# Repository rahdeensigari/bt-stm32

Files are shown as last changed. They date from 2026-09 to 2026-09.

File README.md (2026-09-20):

# bt-stm32
An STM32 board with Bluetooth capabilities, made primarily for the sake of practice. I'm making this mainly so I can improve my PCB design skill all around, but mainly to practice making 4-layer boards, as well as to practice SMD soldering. I'm following along with [this](https://www.youtube.com/watch?v=nkHFoxe0mrU) tutorial (with my own changes, of course) to make this board using KiCAD. Firmware wise, I'm currently only using a basic script to flash the onboard LED on and off, but I will change this as I see fit, and all revisions will be updated to the repo.





If you want to make this for whatever reason, I would HIGHLY recommend using an SMD stencil instead of JLCPCB's PCBA, the gerbers and the BOM are in the [production](/production) folder. You can also find the firmware, which is currently just a basic LED blink, in the [firmware](/firmware) folder, and the PCB files themselves in the [pcb](/pcb) folder.

Some general cost estimates (USD):
- PCB: $7.10
- Stencil: $7.22
- LCSC Components: $31.01

If you want to use the RF capabilities, you will need an external antenna. Just search up female U.FL antenna and you will be able to find a lot of antennas that will work perfectly fine.

*Submitted to Forge (Hackclub)*
*Credit to Phil's Lab and Claude*

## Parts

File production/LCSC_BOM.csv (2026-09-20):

Index | LCSC# | MPN | Manufacturer | Package | Customer # | Description | RoHS | Quantity | MOQ | Multiple | Unit Price($) | Extended Price($) | Product Link
1 | C184029 | LQW15AN10NJ00D | muRata | 0402 |  | 500mA 10nH ±5% 170mΩ Unshielded Inductor 0402 Fixed Inductors RoHS | yes | 20 | 20 | 20 | 0.0420 | 0.84 | https://www.lcsc.com/product-detail/C184029.html
2 | C843260 | NX2016SA-32MHZ-STD-CZS-5 | NDK | SMD2016-4P |  | SMD2016-4P Crystals | yes | 5 | 5 | 5 | 0.3534 | 1.77 | https://www.lcsc.com/product-detail/C843260.html
3 | C54930595 | NXPC32.768KAE125F-BT-5 | NSK | SMD2012 |  | ±20ppm 12.5pF ±20ppm SMD2012 Crystals | yes | 1 | 1 | 1 | 0.4317 | 0.43 | https://www.lcsc.com/product-detail/C54930595.html
4 | C911135 | STM32WB55CEU6 | ST | UFQFPN-48(7x7) |  | ARM Cortex-M4 32 Bit 1.71V~3.6V UFQFPN-48(7x7) RF Transceiver ICs RoHS | yes | 1 | 1 | 1 | 8.5087 | 8.51 | https://www.lcsc.com/product-detail/C911135.html
5 | C7519 | USBLC6-2SC6 | ST | SOT-23-6L |  | 17VC Clamp 5A Ipp ESD DIODE SOT-23-6L | yes | 5 | 5 | 5 | 0.1782 | 0.89 | https://www.lcsc.com/product-detail/C7519.html
6 | C11337 | TLV70033DDCR | TI | SOT-23-5 |  | 3.3V Positive Fixed SOT-23-5 Voltage Regulators - Linear, Low Drop Out (LDO) Regulators RoHS | yes | 5 | 5 | 5 | 0.1739 | 0.87 | https://www.lcsc.com/product-detail/C11337.html
7 | C49234124 | HX 3x4x2-2P-1.6N TACTILE SWITCH | hanxia | SMD,4x3mm |  | Tactile Switch SPST 160gf 2mm SMD (SMT) Tab 4mm x 3mm Surface Mount | yes | 20 | 20 | 20 | 0.0240 | 0.48 | https://www.lcsc.com/product-detail/C49234124.html
8 | C25091 | 0402WGF2200TCE | UNI-ROYAL | 0402 |  | 220Ω ±1% 62.5mW 0402 Thick Film Resistor | yes | 100 | 100 | 100 | 0.0033 | 0.33 | https://www.lcsc.com/product-detail/C25091.html
9 | C105872 | RC0402FR-075K1L | YAGEO | 0402 |  | 5.1kΩ 62.5mW 50V Thick Film Resistor ±100ppm/℃ ±1% 0402 Chip Resistor - Surface Mount RoHS | yes | 100 | 100 | 100 | 0.0026 | 0.26 | https://www.lcsc.com/product-detail/C105872.html
10 | C77108 | LQG15HS2N7S02D | muRata | 0402 |  | 800mA 2.7nH 150mΩ Multilayer inductor 0402 Fixed Inductors RoHS | yes | 50 | 50 | 50 | 0.0216 | 1.08 | https://www.lcsc.com/product-detail/C77108.html
11 | C963809 | EBLS201209-100K | HYHONGYEX | 0805 |  | 15mA 10uH ±10% 1.15Ω Multilayer inductor 0805 Fixed Inductors RoHS | yes | 20 | 20 | 20 | 0.0389 | 0.78 | https://www.lcsc.com/product-detail/C963809.html
12 | C60474 | CC0402KRX7R7BB104 | YAGEO | 0402 |  | 100nF ±10% 16V Ceramic Capacitor X7R 0402 | yes | 100 | 100 | 100 | 0.0050 | 0.50 | https://www.lcsc.com/product-detail/C60474.html
13 | C598199 | U.FL-R-SMT-1(01) | HRS | SMD |  | Connector Receptacle IPEX Male Pin 50Ω Surface Mount | yes | 1 | 1 | 1 | 3.4577 | 3.46 | https://www.lcsc.com/product-detail/C598199.html
14 | C492398 | PM127V-11-04P-H34 | XFCN | Through Hole,P=1.27mm |  | Female Header 4 Position 1.27mm Pitch Single Row Through Hole -40℃~+105℃ | yes | 5 | 5 | 5 | 0.0988 | 0.49 | https://www.lcsc.com/product-detail/C492398.html
15 | C22438072 | HX PM1.27-1x6P ZC | hanxia | Through Hole,P=1.27mm |  | Female Header 6 Position 1.27mm Pitch Single Row Through Hole -40℃~+105℃ | yes | 5 | 5 | 5 | 0.1270 | 0.64 | https://www.lcsc.com/product-detail/C22438072.html
16 | C2894897 | HC-TYPE-C-16P-01A | HCTL | SMD |  | USB-C (USB TYPE-C) Receptacle Connector 16 Position Surface Mount, Right Angle | yes | 5 | 5 | 5 | 0.0848 | 0.42 | https://www.lcsc.com/product-detail/C2894897.html
17 | C531364 | DLF162500LT-5028A1 | TDK | SMD-4P,1.6x0.8mm |  | 50Ω 0.33dB SMD-4P,1.6x0.8mm RF Filters RoHS | yes | 5 | 5 | 5 | 0.1252 | 0.63 | https://www.lcsc.com/product-detail/C531364.html
18 | C21260817 | YLED0402R | YONGYUTAI | 0402 |  | Red 645nm LED Indication - Discrete 1.8V~2.4V 0402 | yes | 50 | 50 | 50 | 0.0134 | 0.67 | https://www.lcsc.com/product-detail/C21260817.html
19 | C76909 | GJM1555C1HR30WB01D | muRata | 0402 |  | 0.3pF 50V Ceramic Capacitor C0G 0402 | yes | 20 | 20 | 20 | 0.0421 | 0.84 | https://www.lcsc.com/product-detail/C76909.html
20 | C88902 | GJM1555C1HR80WB01D | muRata | 0402 |  | 0.8pF 50V Ceramic Capacitor C0G 0402 | yes | 20 | 20 | 20 | 0.0404 | 0.81 | https://www.lcsc.com/product-detail/C88902.html
21 | C161306 | GJM1555C1H130FB01D | muRata | 0402 |  | 13pF ±1% 50V Ceramic Capacitor C0G 0402 | yes | 10 | 10 | 10 | 0.0537 | 0.54 | https://www.lcsc.com/product-detail/C161306.html
22 | C106200 | CC0402JRNPO9BN101 | YAGEO | 0402 |  | 100pF ±5% 50V Ceramic Capacitor NP0 0402 | yes | 100 | 100 | 100 | 0.0044 | 0.44 | https://www.lcsc.com/product-detail/C106200.html

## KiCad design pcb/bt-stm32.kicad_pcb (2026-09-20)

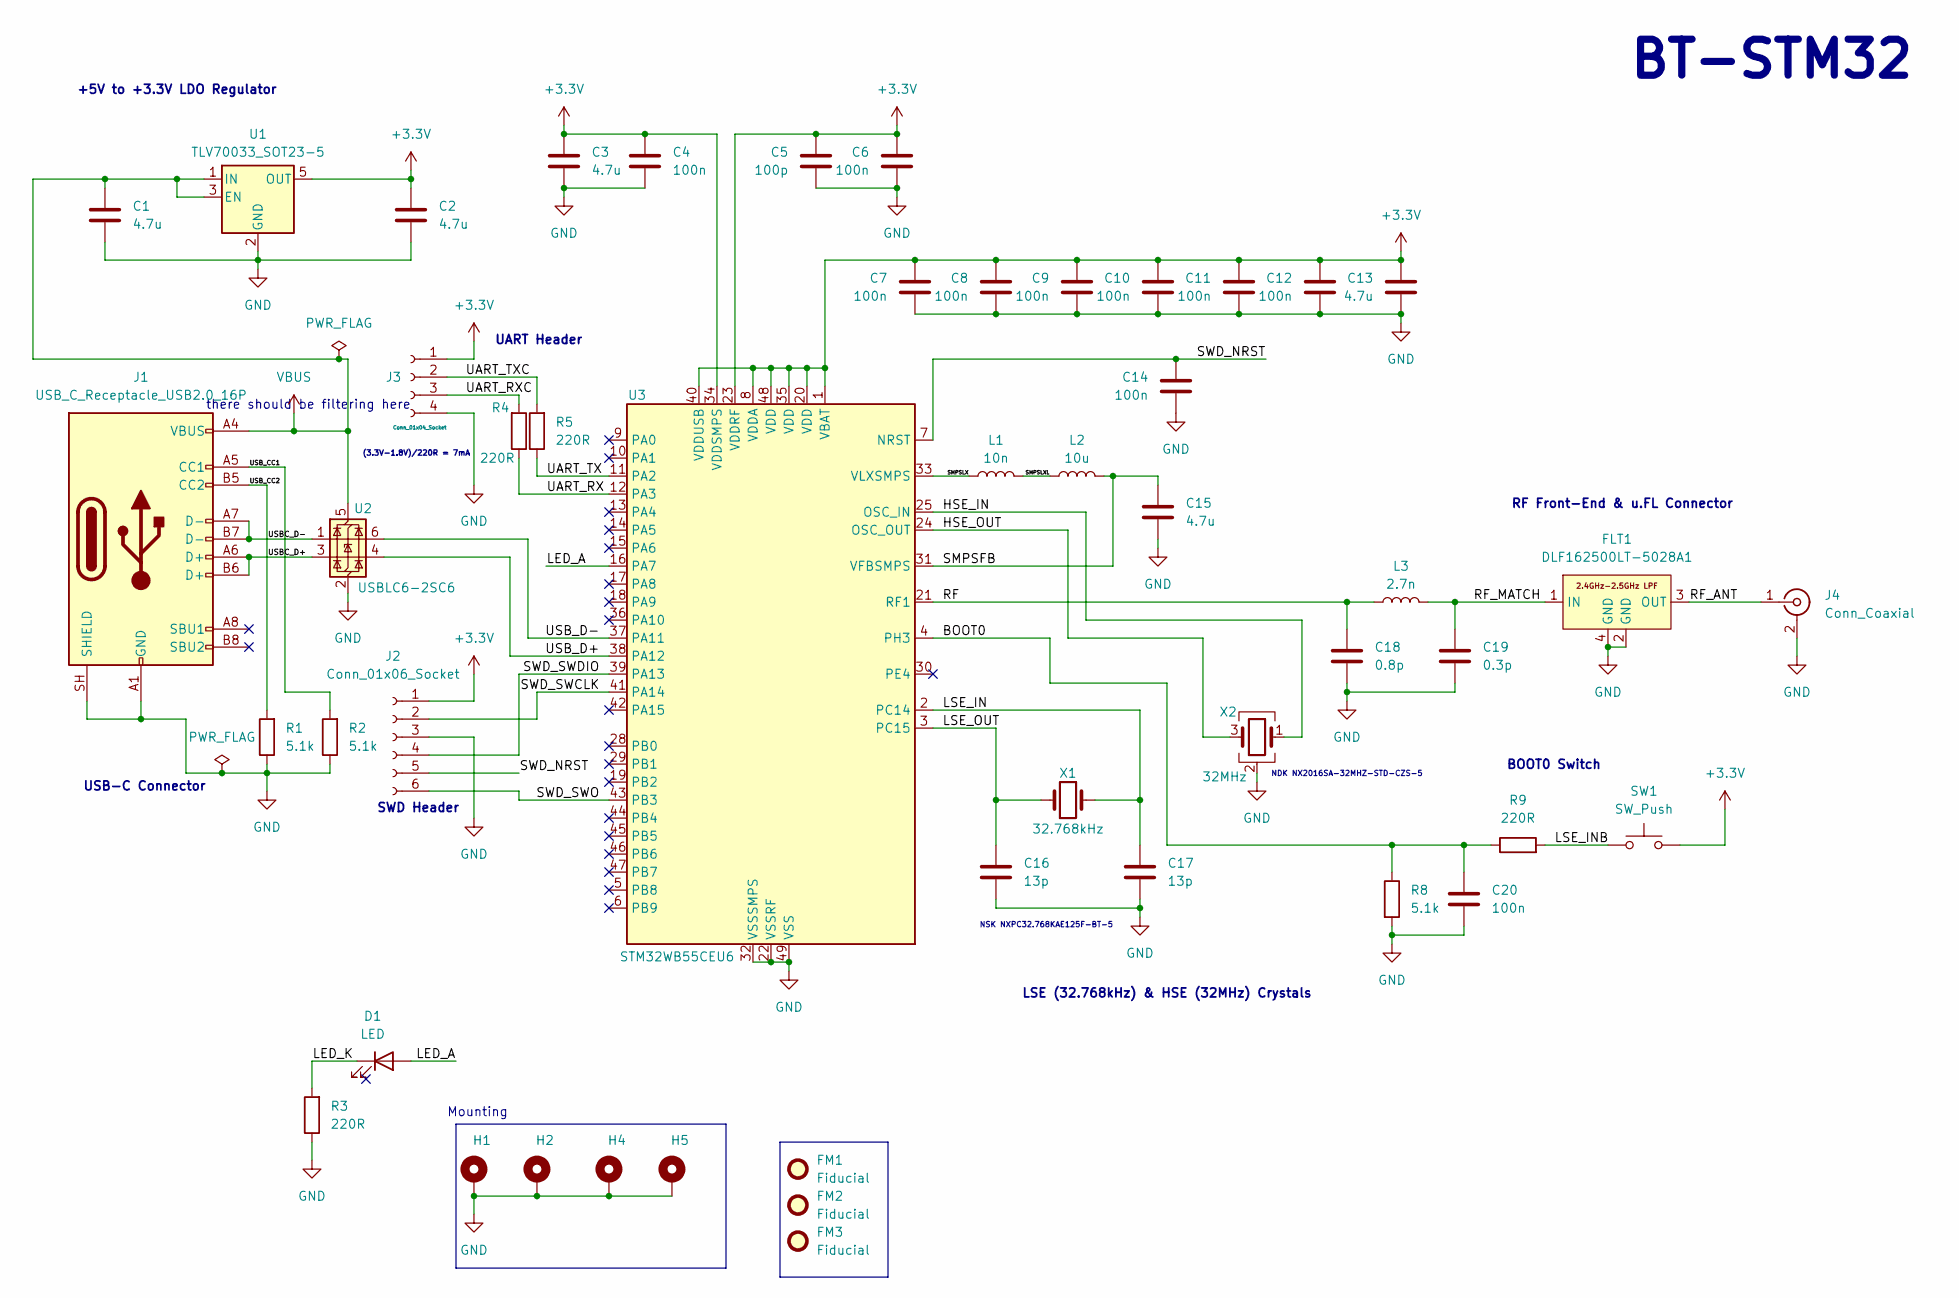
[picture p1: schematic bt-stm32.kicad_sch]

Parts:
C1, C2, C3: 4.7u; C_0603_1608Metric; Part Number C1705
C4, C6, C7, C8, C9, C10, C11, C12, C14, C20: 100n; C_0402_1005Metric; Part Number C60474
C5: 100p; C_0402_1005Metric; Part Number C106200
C13, C15: 4.7u; C_0603_1608Metric; Part Number C368809
C16, C17: 13p; C_0402_1005Metric; Part Number C161306
C18: 0.8p; C_0402_1005Metric; Part Number C88902
C19: 0.3p; C_0402_1005Metric; Part Number C76909
D1: LED; LED_0402_1005Metric; Part Number C21260817
FLT1: DLF162500LT-5028A1; Part Number C531364
FM1, FM2, FM3: Fiducial; Fiducial_1mm_Mask2mm
H1, H2, H4, H5: MountingHole_Pad; MountingHole_2.2mm_M2_Pad_Via
J1: USB_C_Receptacle_USB2.0_16P; USB_C_Receptacle_HCTL_HC-TYPE-C-16P-01A; Part Number C2894897
J2: Conn_01x06_Socket; PinHeader_1x06_P1.27mm_Vertical; Part Number C22438072
J3: Conn_01x04_Socket; PinHeader_1x04_P1.27mm_Vertical; Part Number C492398
J4: Conn_Coaxial; U.FL_Hirose_U.FL-R-SMT-1_Vertical; Part Number C598199
L1: 10n; L_0402_1005Metric; Part Number C184029
L2: 10u; L_0805_2012Metric; Part Number C963809
L3: 2.7n; L_0402_1005Metric; Part Number C77108
R1, R2, R8: 5.1k; R_0402_1005Metric; Part Number C105872
R3, R4, R5, R9: 220R; R_0402_1005Metric; Part Number C25091
SW1: SW_Push; SMD,4x3mm; Part Number C49234124
U1: TLV70033_SOT23-5; SOT-23-5; Part Number C11337
U2: USBLC6-2SC6; SOT-23-6; Part Number C7519
U3: STM32WB55CEU6; QFN-48-1EP_7x7mm_P0.5mm_EP5.6x5.6mm; Part Number C911135
X1: 32.768kHz; Crystal_SMD_2012-2Pin_2.0x1.2mm; Part Number C54930595
X2: 32MHz; Crystal_SMD_2016-4Pin_2.0x1.6mm; Part Number C843260

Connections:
+3.3V: C2.1, C3.1, C4.1, C5.1, C6.1, C7.1, C8.1, C9.1, C10.1, C11.1, C12.1, C13.1, J2.1, J3.1, SW1.2, U1.5 (OUT), U3.1 (VBAT), U3.8 (VDDA), U3.20 (VDD), U3.23 (VDDRF), U3.34 (VDDSMPS), U3.35 (VDD), U3.40 (VDDUSB), U3.48 (VDD)
/BOOT0: C20.1, R8.1, R9.1, U3.4 (PH3)
/HSE_IN: U3.25 (OSC_IN), X2.1
/HSE_OUT: U3.24 (OSC_OUT), X2.3
/LED_A: D1.2 (A), U3.16 (PA7)
/LED_K: D1.1 (K), R3.2
/LSE_IN: C17.1, U3.2 (PC14), X1.1
/LSE_INB: R9.2, SW1.1
/LSE_OUT: C16.1, U3.3 (PC15), X1.2
/RF: C18.1, L3.2, U3.21 (RF1)
/RF_ANT: FLT1.3 (OUT), J4.1 (In)
/RF_MATCH: C19.1, FLT1.1 (IN), L3.1
/SMPSFB: C15.1, L2.1, U3.31 (VFBSMPS)
/SMPSLX: L1.2, U3.33 (VLXSMPS)
/SMPSLXL: L1.1, L2.2
/SWD_NRST: C14.1, J2.5, U3.7 (NRST)
/SWD_SWCLK: J2.2, U3.41 (PA14)
/SWD_SWDIO: J2.4, U3.39 (PA13)
/SWD_SWO: J2.6, U3.43 (PB3)
/UART_RX: R4.1, U3.12 (PA3)
/UART_RXC: J3.3, R4.2
/UART_TX: R5.1, U3.11 (PA2)
/UART_TXC: J3.2, R5.2
/USBC_D+: J1.A6 (D+), J1.B6 (D+), U2.3 (I/O2)
/USBC_D-: J1.A7 (D-), J1.B7 (D-), U2.1 (I/O1)
/USB_CC1: J1.A5 (CC1), R2.2
/USB_CC2: J1.B5 (CC2), R1.2
/USB_D+: U2.4 (I/O2), U3.38 (PA12)
/USB_D-: U2.6 (I/O1), U3.37 (PA11)
GND: C1.2, C2.2, C3.2, C4.2, C5.2, C6.2, C7.2, C8.2, C9.2, C10.2, C11.2, C12.2, C13.2, C14.2, C15.2, C16.2, C17.2, C18.2, C19.2, C20.2, FLT1.2 (GND), FLT1.4 (GND), H1.1 (1_1), H2.1 (1_1), H4.1 (1_1), H5.1 (1_1), J1.A1 (GND), J1.A12 (GND), J1.B1 (GND), J1.B12 (GND), J1.SH (SHIELD), J2.3, J3.4, J4.2 (Ext), R1.1, R2.1, R3.1, R8.2, U1.2 (GND), U2.2 (GND), U3.22 (VSSRF), U3.32 (VSSSMPS), U3.49 (VSS), X2.2 (G), X2.4 (G)
VBUS: C1.1, J1.A4 (VBUS), J1.A9 (VBUS), J1.B4 (VBUS), J1.B9 (VBUS), U1.1 (IN), U1.3 (EN), U2.5 (VBUS)

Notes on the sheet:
USB-C Connector
NSK NXPC32.768KAE125F-BT-5
UART Header
Mounting
there should be filtering here
BT-STM32
+5V to +3.3V LDO Regulator
SWD Header
(3.3V-1.8V)/220R = 7mA
NDK NX2016SA-32MHZ-STD-CZS-5
RF Front-End & u.FL Connector
LSE (32.768kHz) & HSE (32MHz) Crystals
BOOT0 Switch

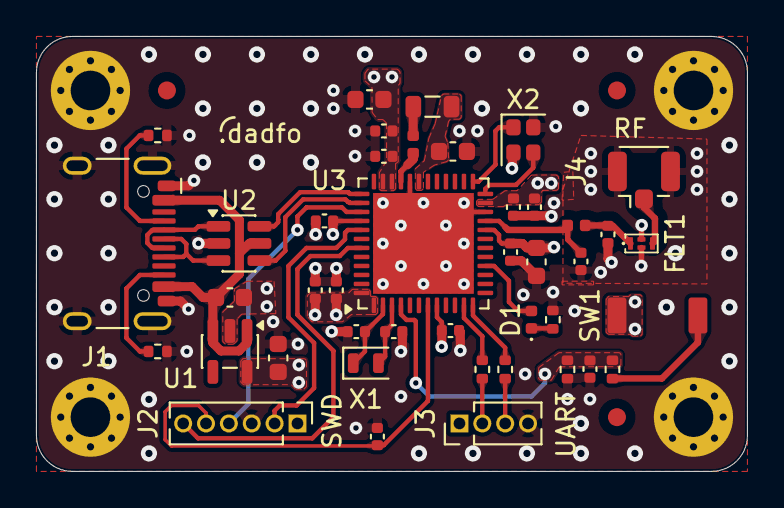
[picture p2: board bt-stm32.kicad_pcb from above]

Board: 4 copper layers, 39.5 x 24.2 mm, 49 parts (0 on the bottom side), 31 nets.

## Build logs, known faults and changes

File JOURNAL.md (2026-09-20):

# August 8 - Start

This is mainly going to serve as a practice exercise for creating 4-layer pcbs. As mentioned in the README, I'm following along with [this](https://www.youtube.com/watch?v=nkHFoxe0mrU) tutorial to create the base board (that's why this is marked as T4 on forge) but I will make some changes to the design as I see fit, and will try to do the majority of steps myself. This board is going to use the STM32WB55CEU6 MCU to allow for Bluetooth communication. I'm also going to be using KiCAD to actually create the schematic and design the PCB. With that out of the way, I'm going to jump straight into designing this. First, I imported the MCU symbol in KiCAD:



Then I also created a new project in STM32CubeMX, which is a software that allows for easier assignment of pins depending on your needs:



Back in KiCAD, I added all of the decoupling caps. These were mostly based off [this](https://www.st.com/resource/en/application_note/an5165-how-to-develop-rf-hardware-using-stm32wb-mcus-stmicroelectronics.pdf) application note. To keep the board relatively simple, I merged VDD, VDDA, and VDDUSB, as well as VBAT of course. The tutorial also didn't add a second 100pF to the VDDRF pin, but I added it just for good measure.



Next I implemented SMPS, this basically helps improve low power performance. I did this by tying the VLXSMPS and VFBSMPS pins together connected by two inductors and a capacitor as specified by the documentation:



Then, I added the crystal oscillators. This MCU is kind of weird in that it requires both a high-speed and low-speed crystal oscillator. The high-speed crystal actually doesn't require any load capacitors as well. For the low-speed crystal's load capacitors, I'm not going to actually add their values until I decide which crystal I'm going to be using.



**Total Time Spent: 1 Hour**

# August 14 - RF Hardware and USB-C

Next up is the RF hardware. This is pretty new to me so I'm going to rely pretty heavily on the tutorial. STM's official application notes (AN5165) say to setup the RF hardware like this:



Using that as a reference, I first setup the matching network. This basically uses pi-network impedance matching to keep the impedance equal on both sides, preventing signal reflection.



Next, I added a low pass filter. The specific model that the application note suggests is DLF162500LT-5028A1, which didn't have a schematic and footprint available, meaning I had to make my own:




Then I added a coaxial connector symbol for the UFL connector.
 


Next I broke out the SWD pins for debugging as well as the reset pin in STM32CubeMX:



Then I added it into the schematic. I'm using a 6 pin connector while the video uses something called a tag-connect, but tag-connect wires are expensive so I'm just going to stick with a simple connector.



Added boot:



Next I added USB-C, this is pretty standard but I also added an ESD protector, which is not something I've actually done in the past:



To find a good LDO voltage regulator, I used STM32CubeMX to find the current requirements for the MCU.



Since it is so low, I can get away with using an LDO voltage regulator. The specific one I'm using is the MIC5365-3.3YD5. I'm using 4.7uF caps to shorten the BOM.



**Total Time Spent: 1.97 Hours**

# August 23 - UART, LED indicator

Next I'm going to add some peripherals, specifically a UART header. This is pretty standard, I'm not going to go too overkill here. I'm using a socket because it's cleaner than pins:




I'm also going to add an LED power indicator. Normally I just hook this up to power, but the tutorial actually uses a timer channel to control it through PWM, which is something new to me. The tutorial uses the PA7 pin, I'm going to use PB9 instead because my schematic is kind of cluttered in the PA7 area:



For the LED, in order for it work properly I need around 220R, so I'm just going to change all the other 100R resistors to 220R as well to simplify the BOM.



The schematic itself is now complete, I just need to clean some stuff up. I added some labels and a title block, as well as fixing KiCAD's automatic annotations. Additionally I assigned 12.5p load caps to the LSE crystal (later changed to 13p as LCSC doesn't have 12.5p)



I then went ahead and assigned footprints to all of my symbols. I also just removed the series resistors for the crystals. One thing I did decide on doing was to change the LDO to a cheaper version (TI TLV70033DDCR). I also updated my symbol fields to include the links to all the parts that I will be using to make ordering them easier (this took up the majority of the time).



I also added some net classes, and that basically finishes the entire schematic.

**Total Time Spent: 2.833 Hours**

# August 24 - Starting the PCB

I'm finally going to start actually designing the PCB. First, I need to do some basic setup. Obviously, this is going to be a 4-layer board (that's literally the reason I'm doing this), and since I'm using RF hardware I also need to make it impedance controlled. I did this by checking the box for it in KiCAD. I also changed the layer thickness and material according to JLCPCB's specs:



I also updated the design rule constraints based off of what JLCPCB allows:



I spent a lot of time after trying to figure out impedance, but it's late so I'll do that later.

**Total Time Spent: 0.66 Hours**

# August 25 - Impedance Research + PCB

I did some [research](https://www.youtube.com/watch?v=0fteCxn5XXA) on impedance so I can find out how to actually calculate the right impedance trace width for this board. From that video, I calculated that I'm going to need a trace width of 0.3586mm. I did this by using [JLCPCB's impedance calculator](https://jlcpcb.com/pcb-impedance-calculator), which greatly simplifies the process of calculating impedance as they have all the dielectric constant of their different board stack-ups built-in. For some reason, the main stack-up type they use is the last option on the calculator, which kind of confused me at first. I also calculated the impedance of the USB differential pair, which, with a target resistance of 90R and spacing of 0.15mm, turned out to be 0.2474mm. I then proceeded to add these as predefined track sizes, along with all the other predefined values that were added from the video, before adding all of my components to the PCB editor:




First thing I did was go into my schematic and add some netlabels in places where I had forgotten them, pretty straightforward. I also didn't have a lot of the 3D models for the components so I went ahead and added all of the ones I didn't have. For the USB-C model, the specific one that I'm going to use doesn't have a STEP model available, so I had to use one of KiCAD's built in ones that didn't quite match but is good enough for this purpose for me to not care.



**Total Time Spent: 0.817 Hours**

# August 29 - Component Layout

The first thing I did was add colors to my net classes to help me during laying out/doing traces on the PCB.



For the actual layout of the PCB, I'm trying a different approach that was used in the video, and that's to first create a very rough layout of the major components and build from there. Before what I did was try to spread out from the MCU to the rest of the board, but this approach feels like I'm planning the entire layout of the board better. The board is going be very long compared to its width, with the USB connector on one side and the RF antenna on the other. I'm kind of just placing stuff both where the video says to place it and where I think it would fit the best.

I originally had the SWD socket lined up vertically like how the video did it with tag connects:



However, after adding the ESD protection on the USB port, I realized that drawing the traces around the socket wouldn't be optimal, so I just moved it down horizontally aligned with the UART socket:



A good workflow that I'm finding effective is to do the thing where you layout all the major components first, but I'm also cleaning up component placements in relation to each other while I'm creating the initial layout. (RF):



Load caps for the LSE crystal. I might change the orientation of the GND pins on the resistors later:



I also realized that I had gotten a couple of caps (C13, C15) wrong in the BOM while I was laying out the components for SMPS:



That's all the important components done, I'll move on to decoupling caps in my next session.



**Total Time Spent: 1.7 Hours**

# August 30 - Smaller Components and Finished Layout

I'm going to start today by placing the decoupling capacitors. I normally do these first, but the video is demanding for them to be done after all the major components have already been laid out. The goal with decoupling capacitors is to have them as close to the MCU as possible, as the less trace between the pins means there's going to be less inductance and noise. I tried to do these myself then go back to the video to see the optimal way to place it. One especially difficult part to place capacitors were pins 34 and 35, which was near the SMPS components. I had to place both of them vertically and shift the SMPS components over slightly in order to make it work. I also had one extra capacitor that the video left out (C6):



At first I thought this would work fine, but then I realized that I would also need a bulk decoupling capacitor for C4. I unfortunately could not figure out how to place them so I did have to resort to seeing what the video did, which was to route the smaller caps in parallel with the bulk decoupling cap at the end:



Everything else was really straightforward, here are the decoupling caps with my placements:



One note, for some reason the video didn't add the second bulk decoupling cap yet, which I added with my other caps. I'm not sure as to why he didn't do this, but I'm guessing it is because it's less important. After looking at what he did, pretty much everything else was the same, except for one of the decoupling caps near the bottom being moved a bit further up to allow the crystal to be closer to the MCU, which I implemented as well:



(Note: He did add it later as well)

Next up, I did the LDO regulator. I tried it myself and I got something like this, with the IC right above the ESC protection and the capacitors around the LDO regulator:



The more optimal design however is to move the LDO regulator below the ESD protector and rotate it 90 degrees like this. This fills in a perfectly shaped dead space near the bottom of my PCB:

 

Then I added the CC1 and CC2 pulldown resistors, not much to say here, these are pretty straightforward. I just have them parallel to the connector so they look better and so it's easier to route:



NRST capacitor. Again, this is pretty simple. I just had to keep in mind how it would be connected from the MCU to the SWD socket:



Next was the LED, and it turns out that my current pinout made routing it a pain, as the traces had to pass through all of the LSE/UART components to actually get to the LED. Instead, I changed the pin from PB9 to PA7, which made the routing a whole lot easier:



Last for the layout, I added the boot switch. I decided to place this in a dead space near the far bottom right of the PCB. Again, not really anything notable, I just added the resistors and caps:



With that though, the layout is complete:




**Total Time Spent: 2.033 Hours**

# August 31 - Board Outline, Mounting Holes, Fiducial Markers

First thing I did today was the board outline. This was really simple, I just defined a basic outline that I can change later on if I need to:



I also added my author indicator:



After that, I was ready to move on to routing. The stack up that the video uses is SIGNAL - GND - GND - SIGNAL but this isn't the standard, so I want to try using SIGNAL - GND - POWER - SIGNAL instead.




Next, I added some mounting holes and fiducial markers in my schematic then laid them out on my PCB. For some reason, the video is tying the mounting holes to ground, which I don't think is necessary but I'll follow along. Also note that because this is a demo board I do not care at all about where I place these:




**Total Time Spent: 0.583 Hours**

# September 4 - Designators and Traces

I started traces. The workflow that the video says to use is to do vias first. Before I started traces though, I wanted to clean up the component indicators, as most actual professional PCBs do not include designators for every single component. Additionally, I have no plans to hand solder this board, so the indicators aren't really helping me either. Instead, I decided to keep only the ones that I deemed important:



With the majority of the designators out of the way, I could re-place some of my components to make the board more uniform, and also add some extra silkscreen notes to important components. The reason I'm doing this first is so I know where I can't place vias. With these changes, I also actually have room for 4 mounting holes now:



As mentioned before, I started with vias. One thing I struggled with was figuring out how to copy and paste the same trace length between different pads and actually get the end of the trace to snap to other pad. I figured out after a bit of research that I needed to set object snapping to all layers for it to actually work. After I figured that out though it was pretty straightforward. I connected the traces for all of the components that only needed one via but left the vias that needed fill zones unconnected for now:



I also went ahead and did the same thing for 3v3:



Now I can move on to actual routing. I started with the RF traces. These were pretty straightforward, but one thing that I'm kind of uncertain of is that I need to have a smaller trace at the actual pin on the STM32 going up to a wider trace (impedance), which I don't really like:




After the RF traces, I did the crystal routing. There was nothing really noteworthy to talk about here, except for the fact that I did have to move some of the capacitors on the LSE crystal to make routing a little bit easier:



The big thing I realized though was how stupid of a decision it was to do SIGNAL - GND - POWER - SIGNAL for this board. Because of this, I'm probably going to switch to SIGNAL - GND - GND - SINGAL tomorrow.

**Total Time Spent: 1.6 hours**

# September 5 - Fixed Stackup, More Traces

As mentioned yesterday, my old stackup was not optimal at all. Because of this, I'm going to change it to SIGNAL - GND - GND - SINGAL. This was a pretty easy fix.

After the crystal routing, I did SMPS. Again, pretty straightforward. An interesting thing I noticed was to start with the largest possible trace width (so 0.25mm) then scale up to a larger width like 0.5mm to reduce impedance.



Next is the SWD traces, and these are just a pain. I faced a couple of problems when trying to route these:

1. The USB differential pair pads are right next to the SWD pads.
2. There are two sets of decoupling capacitors above and below the SWD pads.
3. The actual socket is very far away, and there are a lot of components blocking the path to it.
4. I wanted to impedance match the traces.

Although I don't have any screenshots of it, I did actually try to move the socket up to the top of the PCB, but this only made it harder to route everything. While I had it moved to the top, I realized I actually messed up the order of the pins, and changed it to what the standard order should be:



Eventually, I moved the socket back down and tried routing the traces through the bottom layer with vias instead. So far this seems to work fine. I decided that I'm going to ignore impedance matching for this, as it is not necessary for SWD to the level that it is necessary for RF traces. It's late, so I'll continue this tommorow:



**Total Time Spent: 1.33 Hours**

# September 6 - Continued Routing Traces

I started today by finishing the SWD traces. I didn't need to do any of the stuff with vias for the other traces, but I might have to change some of them if there is interference with other routing:



Next, I went ahead and did the USB differential pairs. These aren't perfectly differential (I changed some parts of the traces to make it neat), but for short lengths like these, it really doesn't matter too much:



That's all the critical traces done. With those out of the way, I can move on to the more low priority stuff. First, I routed the BOOT0 pins. These were really annoying to route. First, to even break it out from the MCU, I had to shift the LSE over, as in its current position it was blocking the BOOT0 pin from being broken out. Then, the next problem was that the NRST trace was blocking the BOOT0 trace. To fix this, I had to use a via to route the trace to the bottom layer and another via to bring it back up. I also connected the capacitors and resistors with a copper pour:



Then, I routed a couple of the easier traces, for example LED and UART. Nothing really notable to state for these, they were pretty straightforward:



I also added some ground return vias to the BOOT0 vias:



I also routed the CC connections on the USB header. Although not necessary, I did take some care to make the traces equal length:



That's actually all of the signal connections done, now all that's left are the power and ground connections. First, I started with the VBUS traces. I did have to remove the via on the top GND pad on the LDO regulator:



Then I worked on routing 3v3. The way I'm going to do this is by using a copper pour on the bottom layer connecting all the vias together, then individual copper pours connecting the 3v3 vias together:




I also did a similar thing with the GND pads using the two middle copper pour layers:



**Total Time Spent: 1.94 Hours**

# September 19 - Finished PCB!

The first thing I did was finish the 3v3 pours:





With that done, I'm actually going to take a different approach do doing the GND connections. Instead of individual pours like I did with 3v3, I'm just going to fill the entire top layer with a GND pour that connects all of the GND vias to each other. To do this, I first deleted all the existing pours and connections that I had before:



Then I added the actual GND pour to the GND plane:



This was a pain, and it's not quite perfect, so let me go over what took so long for this. First of all, I had to change the position of most of the GND vias, because they were only partially in the pour zones. This was easy enough, it just took a bit. The main difficulty though was the RF section, because having more copper around it changes the impedance. The best way to fix this is by adding clearance around the RF section, specifically 3x the thickness of the dielectric layers, which was 0.6mm for me. What took me so long was figuring out how to do this, because the video changes the clearance of the entire GND pour, but since he was using PCBWay, the dielectric layers were thinner, allowing him to use less clearance. 0.6mm of clearance around the entire board is just not acceptable, so I spent a long time figuring out how to actually do this. My initial thought was a keep out zone, but this just prevented me from connecting the vias effectively. Eventually, I decided on adding a custom rule area then defining a 0.6mm clearance for anything in that area. (Credit to Claude for figuring this out):




Next, since I have 3 GND planes, I'm going to add some via stitching to minimize impedance across all of the planes. Using this formula:



I calculated the ideal spacing for my vias, which was around 3mm:



With that value, I added stitching vias throughout the entire board:



The PCB is pretty much done now. I added teardrops to all of the pads/traces. I might remove this later, but they're pretty beneficial for now:



I also cleaned up unused vias/pads.

Next was DRC. Initially I was getting this error:



But after checking JLCPCB's capabilities and changing the constraint in the board settings, it fixed itself. All the other errors were just weird track clearances and pretty straightforward to fix, with a couple exceptions.

The first one was this clearance error between two parts of the USB-C footprint:



I fixed this by changing the size of the pads on the footprint:



It also turns out that the RF_Clearance thing from earlier didn't quite work, instead I removed it and replaced it with a secondary GND pour that had higher clearance and priority. The unfortunate thing is that there are some minor gaps in the copper pour now, but they're so small that I don't care:



The next error was that there weren't enough spokes on some of the thermal reliefs throughout the board. I fixed this with a mix of adding traces, keep out zones, and extra GND fills:




I also had a really weird error where the GND plane wasn't connected to itself, but it kind of just fixed itself. I think the reason why was because I got rid of a piece of ground pour that was sitting under a trace not connected to anything.

There were a couple warnings but nothing major, but after that I'm basically done with the entire PCB:




To prepare my project for submission and manufacturing, I did the following:
- Exported the BOM and added it to [the production folder](/production).
- Used the JLCPCB fabrication toolkit to export the other files and added them to [the production folder](/production).
- Ran through JLCPCB to see the price

After running the board through JLCPCB, the price of everything would be over $100. Because of this, I'm going to SMD solder this by hand, it's something I should learn how to do anyways.

Big gap in the time spent in this entry here, but I basically just created orders in JLCPCB and LCSC for the components and updated the repo with the necessary items I need to get the project approved. This was insanely boring.

Before I submit this project, I want to create some basic firmware. I first generated the initial code with STM32CubeMX, then setup VSCode to work as STM32CubeIDE. This took a while to figure out, and I didn't really during this time, so excuse me for the poor documentation here. I had to research how to setup the STM32CubeIDE extension on VSCode and cmake, and I had a lot of stupid problems that took a while to fix (for example, I didn't see a button on the bottom right to install the necessary dependencies and was stuck trying to figure out why the extension wasn't working). I also had a problem once everything was setup where I was getting a lot of seemingly random errors, it turned out I just had to rebuild my project and everything worked fine. In case you can't tell, programming is not my strong suit. My actual code is just going to be a simple LED blink for now, but I will change this later if I need to, for now I just want to make sure the board won't exploded on me. I pushed the code to the firmware folder in the repo, but it was pretty straightforward, here is a simplification of it:

```c
const uint16_t LED_PORT = GPIOA;
const uint16_t LED_PIN = GPIO_PIN_7;

// ...

while (1)
  {
    /* USER CODE END WHILE */

    /* USER CODE BEGIN 3 */
    HAL_GPIO_TogglePin(LED_PORT, LED_PIN);
    HAL_Delay(500);
  }
```

After that, I added some more to my README and uploaded the actual PCB files which I forgot to do earlier. With that, I'm essentially done with the project!

**Total Time Spent: 6.97 Hours**

# Reviewer Note:

Hey, thanks for looking at my project! Some clarification: this PCB was made for practice, not for any use in particular (though I will probably find one), that's why there's not an enclosure or anything for it, because I literally have nothing to enclose it for. The BOM is in the production folder, [LCSC_BOM.csv](production/LCSC_BOM.csv) has the prices for the components. The firmware currently does not do anything related to RF, it literally just blinks the onboard LED. Again, as mentioned earlier, I don't currently have a use for this board, but as soon as I find will I will of course update this repo to fit. Thanks!


**Total Time Spent: 0 Hours**

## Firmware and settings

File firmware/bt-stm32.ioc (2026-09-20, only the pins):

Mcu.UserName=STM32WB55CEUx
PA11.Signal=USB_DM
PA12.Signal=USB_DP
PA13.Signal=SYS_JTMS-SWDIO
PA14.Signal=SYS_JTCK-SWCLK
PA2.Signal=LPUART1_TX
PA3.Signal=LPUART1_RX
PA7.GPIO_Label=LED
PA7.Signal=GPIO_Output
PB3.Signal=SYS_JTDO-SWO
PB9.Signal=S_TIM17_CH1
PC14-OSC32_IN.Signal=RCC_OSC32_IN
PC15-OSC32_OUT.Signal=RCC_OSC32_OUT
